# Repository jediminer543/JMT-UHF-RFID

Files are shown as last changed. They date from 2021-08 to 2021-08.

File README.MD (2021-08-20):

# The UHF-RFID project

This project aims to do build a working UHF RFID reader (ISO 18000-6C thing) using a pair of CC1101s.

But why the hell would you want to do this? Simple. The silicon to do UHF RFID tag reading goes for around $30 per chip in low volumes, dropping to $20 in high volumes. The entire main devboard, fully assembled, cost a grand total of $10 per board.

Given the anciliary components (MCU, Antennas, PowerRegs, PowerAmps, etc.) are likely to cost that again, BOM Cost for a reader built with this scheme is likely $20-30 total, which even at a 2.5x profit maring would still be competetive with the cheapest readers avalible on sites like Aliexpress.

## But why do you care?

UHF RFID allows for the reading of passive tags at up to 15m ranges for some tags. 15m would happen to helpfully cover most houses.

Further depending on which research you look at, these tags have localisability to below 10cm.

Combining these two features, if a many reader system were viable and cheap, it could make losing things a thing of the past. Or just make sure that places stay tidy

## Project state

I have the boards fabbed and assembled; I need to get some more RF stuff fabbed but it's just striplines so should be cheap to make.

Successful communication to the tags was achieved, but return linking failed due to the requirement for a circulator esque device, which has been designed acording to the specifications of [this paper](https://www.researchgate.net/publication/224684549_A_Passive_Circulator_for_RFID_Application_with_High_Isolation_using_a_Directional_Coupler) and simulated with QUCS. These still need to be fabricated.

The code for the project is very much unoptimised; spending far too long doing bitsetting, but this was done intentionally for ease of tweaking; future software improvements will occur if/when the project progresses.

## Why is this on github?

Two reasons. Firstly to share with the world so someone else can hopefully learn or develop something from it

Secondly, because I'm applying for some jobs and saying "here's a thing I made and the source for it" seems fun.

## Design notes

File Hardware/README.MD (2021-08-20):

## Hardware stuff

The devboard folder contains all the files used for the creation of the current devboard, including JLC assemblable gerbers.

The circulator folder contains the files for the circulator in theory, but the results have yet to be validated in the real world

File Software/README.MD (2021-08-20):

## Software

This is the currently built software; made to run on an ESP32 devkit and the dev boards used as part of the project

If you can find yourselves some SMA capible CC1101 boards then you can just use them instead. I couldn't which is why I built my own hardware.

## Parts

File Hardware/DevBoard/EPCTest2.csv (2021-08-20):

Comment | Designator | Footprint | LCSC | LCSC | Price | Field4 | Field5 | Field6 | Field7
100pF | C10,C26 | Capacitors_SMD:C_0603 |  | C14858 | 0.002882
27pF | C11,C12,C27,C28 | Capacitors_SMD:C_0603 |  | C1656 | 0.011736
100nF | C2,C18 | Capacitors_SMD:C_0603 |  | C14663
1pF | C3,C19 | Capacitors_SMD:C_0603 |  | C23969
12pF | C4,C20 | Capacitors_SMD:C_0603 |  | C38523
1.5pF | C5,C1,C21,C17 | Capacitors_SMD:C_0603 |  | C1639
3.3pF | C6,C22 | Capacitors_SMD:C_0603 |  | C85300
47pF | C7,C23 | Capacitors_SMD:C_0603 |  | C1671
DC | C8,C13,C14,C9,C15,C16,C24,C29,C30,C25,C31,C32 | Capacitors_SMD:C_0603 |  | C14663 | 0.007651
CommonSPI | J1 | Pin_Headers:Pin_Header_Straight_1x07_Pitch2.54mm |  | DNP | 0
GDO | J2 | Pin_Headers:Pin_Header_Straight_1x04_Pitch2.54mm |  | DNP | 0
CombOut | J3 | Connectors:SMA_THT_Jack_Straight |  | DNP | 1.12
Local RF Out | J4,J6 | Connectors:SMA_THT_Jack_Straight |  | DNP | 1.12
DigitalIO | J5,J7 | Pin_Headers:Pin_Header_Straight_1x08_Pitch2.54mm |  | DNP | 0
ISO_RX | JP1 | Resistors_SMD:R_0603 |  | DNP | 0.002705
ISO_TX | JP2 | Resistors_SMD:R_0603 |  | DNP | 0.002705
18nH | L2,L7,L9,L14 | Inductors_SMD:L_0603 |  | C86133 | 0.050628
12nH | L5,L1,L3,L4,L12,L8,L10,L11 | Inductors_SMD:L_0603 |  | C29258 | 0.034201
3.3nH | L6,L13 | Inductors_SMD:L_0603 |  | C1029 | 0.006151
PICross | R1 | Resistors_SMD:R_0603 |  | DNP | 0.005
PILeg | R3,R2 | Resistors_SMD:R_0603 |  | DNP | 0.005
TeeCross | R4,R5 | Resistors_SMD:R_0603 |  | DNP | 0.005
TeeLeg | R6 | Resistors_SMD:R_0603 |  | DNP | 0.005
56K | R7,R8 | Resistors_SMD:R_0603 |  | C23206 | 0.000769
CC1101 | U1,U2 | Housings_DFN_QFN:QFN-20-1EP_4x4mm_Pitch0.5mm |  | C29953 | 1.604545 | - | 55R2471 | QFN-20 | CC1101RGP
26Mhz | Y2,Y1 | Crystals:Crystal_SMD_3225-4pin_3.2x2.5mm |  | C70573 | 0.094375

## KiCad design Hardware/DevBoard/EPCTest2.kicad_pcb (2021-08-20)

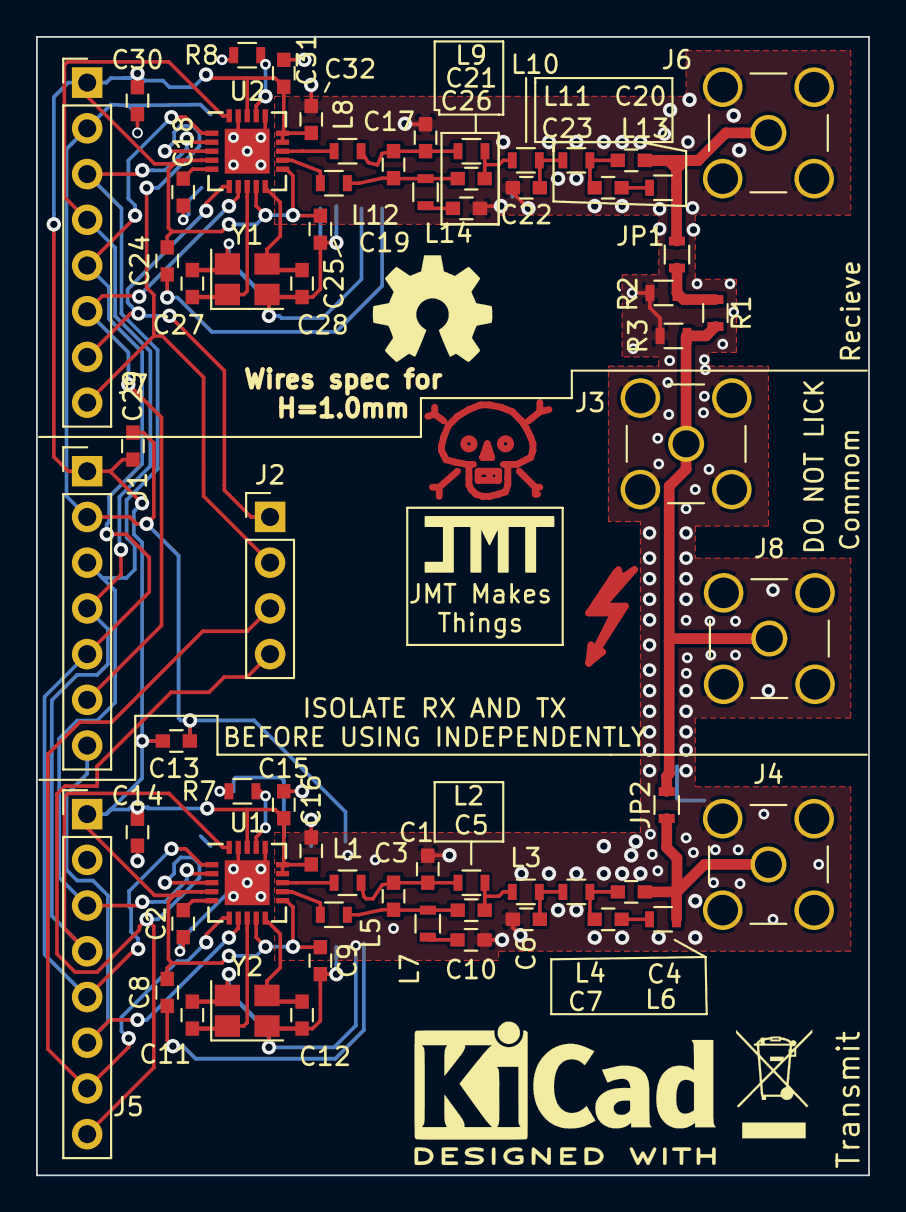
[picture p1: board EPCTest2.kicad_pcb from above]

Board: 2 copper layers, 46.2 x 63.2 mm, 70 parts (0 on the bottom side), 41 nets.

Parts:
 : WEEE; WEEE-Logo_4.2x6mm_SilkScreen
 #2: KiCad; KiCad-Logo2_8mm_SilkScreen
 #3: DANGER; Symbol_Danger_CopperTop_Small
 #4: OSHW; OSHW-Symbol_6.7x6mm_SilkScreen
C1, C5, C17, C21: 1.5pF; C_0603
C2, C18: 100nF; C_0603
C3, C19: 1pF; C_0603
C4, C20: 12pF; C_0603
C6, C22: 3.3pF; C_0603
C7, C23: 47pF; C_0603
C8, C9, C13, C14, C15, C16, C24, C25, C29, C30, C31, C32: DC; C_0603
C10, C26: 100pF; C_0603
C11, C12, C27, C28: 27pF; C_0603
DO NOT LICK: Zap; Symbol_Highvoltage_Type1_CopperTop_Small
J1: CommonSPI; Pin_Header_Straight_1x07_Pitch2.54mm
J2: GDO; Pin_Header_Straight_1x04_Pitch2.54mm
J3: CombOut; SMA_THT_Jack_Straight
J4, J6: Local RF Out; SMA_THT_Jack_Straight
J5, J7: DigitalIO; Pin_Header_Straight_1x08_Pitch2.54mm
J8: Amped In; SMA_THT_Jack_Straight
JP1: ISO_RX; R_0603
JP2: ISO_TX; R_0603
L1, L3, L4, L5, L8, L10, L11, L12: 12nH; L_0603
L2, L7, L9, L14: 18nH; L_0603
L6, L13: 3.3nH; L_0603
R1: PICross; R_0603
R2, R3: PILeg; R_0603
R7, R8: 56K; R_0603
U1, U2: CC1101; QFN-20-1EP_4x4mm_Pitch0.5mm
Y1, Y2: 26Mhz; Crystal_SMD_3225-4pin_3.2x2.5mm

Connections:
+3V3: C8.1, C9.1, C13.1, C14.1, C15.1, C16.1, C24.1, C25.1, C29.1, C30.1, C31.1, C32.1, J1.1, J5.1, J7.1, U1.4, U1.9, U1.11, U1.14, U1.15, U1.18, U2.4, U2.9, U2.11, U2.14, U2.15, U2.18
/CSnRX: J1.6, J7.6, U2.7
/CSnTX: J1.7, J5.6, U1.7
/GDO0_RX: J2.1, J7.7, U2.6
/GDO0_TX: J2.3, J5.7, U1.6
/GDO2_RX: J2.2, J7.8, U2.3
/GDO2_TX: J2.4, J5.8, U1.3
/MISO: J1.3, J5.3, J7.3, U1.2, U2.2
/MOSI: J1.4, J5.4, J7.4, U1.20, U2.20
/RFLeft/DCOUPL: C18.2, U2.5
/RFLeft/RBIAS: R8.2, U2.17
/RFLeft/RF1_N: C17.2, C19.1, L8.2, L9.1
/RFLeft/RF1_P: C19.2, C21.2, L12.1, L14.1
/RFLeft/RF_N: L8.1, U2.13
/RFLeft/RF_P: L12.2, U2.12
/RFLeft/RF_SE: C20.2, J6.1, JP1.1, L13.1
/RFLeft/XOSC1: C27.1, U2.8, Y1.1
/RFLeft/XOSC2: C28.1, U2.10, Y1.3
/RFRight/DCOUPL: C2.2, U1.5
/RFRight/RBIAS: R7.2, U1.17
/RFRight/RF1_N: C1.2, C3.1, L1.2, L2.1
/RFRight/RF1_P: C3.2, C5.2, L5.1, L7.1
/RFRight/RF_N: L1.1, U1.13
/RFRight/RF_P: L5.2, U1.12
/RFRight/RF_SE: C4.2, J4.1, JP2.1, L6.1
/RFRight/XOSC1: C11.1, U1.8, Y2.1
/RFRight/XOSC2: C12.1, U1.10, Y2.3
/RF_RX: JP1.2, R1.1, R2.2
/RF_RX_ATT: J3.1, J8.1, JP2.2, R1.2, R3.2
/SCLK: J1.5, J5.5, J7.5, U1.1, U2.1
GND: C1.1, C2.1, C6.2, C8.2, C9.2, C10.2, C11.2, C12.2, C13.2, C14.2, C15.2, C16.2, C17.1, C18.1, C22.2, C24.2, C25.2, C26.2, C27.2, C28.2, C29.2, C30.2, C31.2, C32.2, J1.2, J3.2, J4.2, J5.2, J6.2, J7.2, J8.2, R2.1, R3.1, R7.1, R8.1, U1.16, U1.19, U1.21, U2.16, U2.19, U2.21, Y1.2, Y1.4, Y2.2, Y2.4
unnamed: C4.1, C7.2, L4.2
unnamed: C5.1, L2.2, L3.1
unnamed: C6.1, L3.2, L4.1
unnamed: C7.1, L6.2
unnamed: C10.1, L7.2
unnamed: C20.1, C23.2, L11.2
unnamed: C21.1, L9.2, L10.1
unnamed: C22.1, L10.2, L11.1
unnamed: C23.1, L13.2
unnamed: C26.1, L14.2

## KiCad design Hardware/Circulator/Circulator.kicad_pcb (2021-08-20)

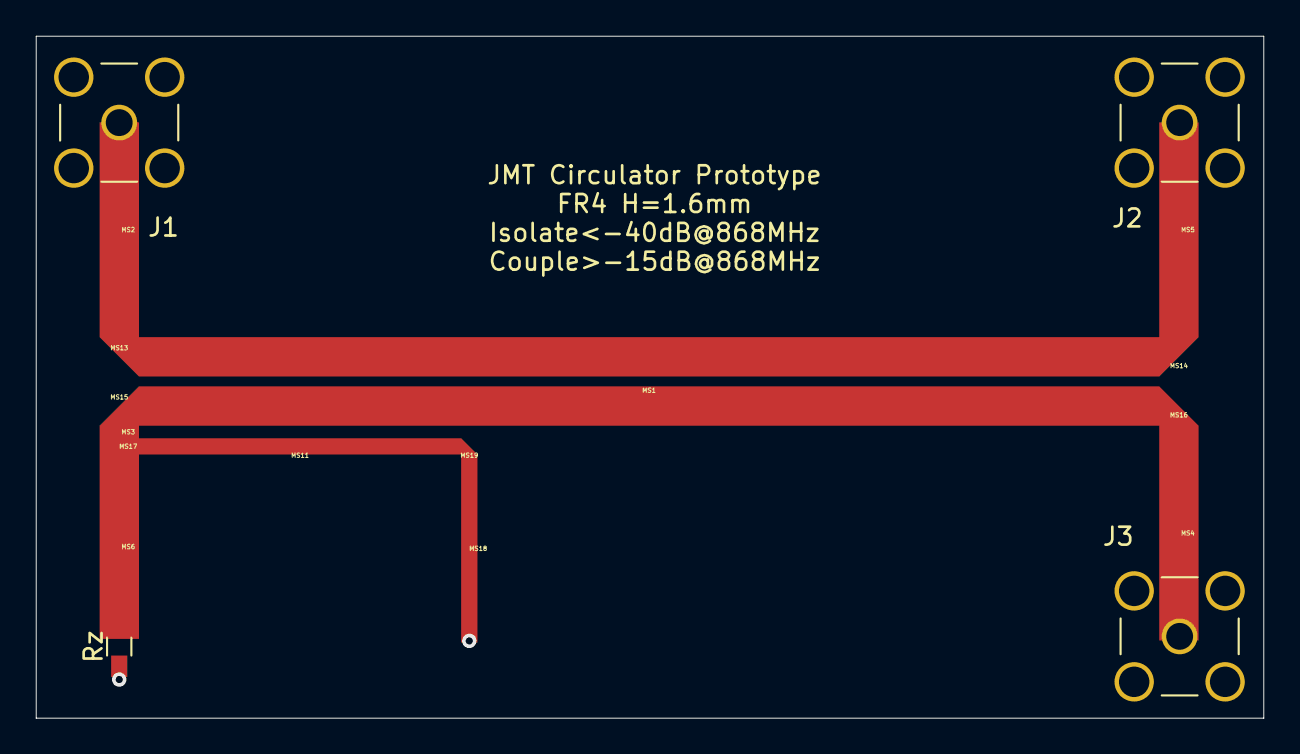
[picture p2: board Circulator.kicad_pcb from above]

Board: 2 copper layers, 68.6 x 38.1 mm, 18 parts (0 on the bottom side), 2 nets.

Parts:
J1, J2, J3: Conn_Coaxial; SMA_THT_Jack_Straight
MS1: microstrip_coupled_lines; MCOUPLED
MS2, MS3, MS4, MS5, MS6, MS11, MS18: microstrip_line; MLIN
MS13, MS14, MS15, MS16, MS19: microstrip_mittered_bend; MMBEND
MS17: microstrip_tee; MTEE
Rz: Rz; R_0603_HandSoldering

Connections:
GND: J1.2, J2.2, J3.1, J3.2, Rz.1
unnamed: J1.1, J2.1

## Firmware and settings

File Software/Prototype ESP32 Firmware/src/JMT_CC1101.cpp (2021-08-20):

#include "JMT_CC1101.h"
#include <Arduino.h>
#include <SPI.h>

uint8_t CC1101_COMMAND(SPIClass* spi, int CSn, uint8_t cmd) {
  spi->beginTransaction(SPISettings(CC1101_GETDR(cmd), MSBFIRST, SPI_MODE0));
  digitalWrite(CSn, LOW);
  uint8_t out = spi->transfer(cmd);
  digitalWrite(CSn, HIGH);
  spi->endTransaction();
  return out;
}

void CC1101_COMMAND(SPIClass* spi, int CSn, int len, uint8_t* dat) {
  spi->beginTransaction(SPISettings(CC1101_GETDR(*dat), MSBFIRST, SPI_MODE0));
  digitalWrite(CSn, LOW);
  for (int i = len-1; i >= 0; i--) {
    *(dat+i) = spi->transfer(*(dat+i));
  }
  digitalWrite(CSn, HIGH);
  spi->endTransaction();
}

void CC1101_COMMAND_REV(SPIClass* spi, int CSn, int len, uint8_t* dat) {
  spi->beginTransaction(SPISettings(CC1101_GETDR(*dat), MSBFIRST, SPI_MODE0));
  digitalWrite(CSn, LOW);
  for (int i = 0; i < len; i++) {
    *(dat+i) = spi->transfer(*(dat+i));
  }
  digitalWrite(CSn, HIGH);
  spi->endTransaction();
}

JCC1101::JCC1101(SPIClass* spi, uint8_t CSn) {
    this->spi = spi;
    this->CSn = CSn;
    pinMode(CSn, OUTPUT);
    digitalWrite(CSn, HIGH);
}

uint8_t JCC1101::command(uint8_t cmd) {
    spi->beginTransaction(SPISettings(CC1101_GETDR(cmd), MSBFIRST, SPI_MODE0));
    digitalWrite(CSn, LOW);
    uint8_t out = spi->transfer(cmd);
    digitalWrite(CSn, HIGH);
    spi->endTransaction();
    return out;
}

void JCC1101::command(int len, uint8_t* dat) {
    spi->beginTransaction(SPISettings(CC1101_GETDR(*dat), MSBFIRST, SPI_MODE0));
    digitalWrite(CSn, LOW);
    for (int i = len-1; i >= 0; i--) {
    *(dat+i) = spi->transfer(*(dat+i));
    }
    digitalWrite(CSn, HIGH);
    spi->endTransaction();
}

void JCC1101::commandRev(int len, uint8_t* dat) {
    spi->beginTransaction(SPISettings(CC1101_GETDR(*dat), MSBFIRST, SPI_MODE0));
    digitalWrite(CSn, LOW);
    for (int i = 0; i < len; i++) {
    *(dat+i) = spi->transfer(*(dat+i));
    }
    digitalWrite(CSn, HIGH);
    spi->endTransaction();
}

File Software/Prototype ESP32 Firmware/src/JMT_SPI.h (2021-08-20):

//SPI BIT ORDERING
#define JMT_SPI_LSBFIRST = 0;
#define JMT_SPI_MSBFIRST = 1;

//SPI MODE; NICKED FROM ARDUINO
#define JMT_SPI_MODE0 = 0;
#define JMT_SPI_MODE1 = 1;
#define JMT_SPI_MODE2 = 2;
#define JMT_SPI_MODE3 = 3;

/**
 * Standard SPI class
 * 
 * Cross platform
 */
class JMTSPI {
  public:
    virtual void beginTransaction() = 0;
    virtual void endTransaction() = 1;
    virtual uint8_t transfer(uint8_t data) = 2;
} JSPI;

/**
 * Arduino version
 */
class JMTASPI : public JMTSPI {
    SPIClass* spi;
    uint8_t pin;
  public:
    JMTASPI(SPIClass* spi, uint8_t pin) {
      this.spi = spi;
      this.pin = pin;
    }
    virtual void beginTransaction() {
      
    }
    virtual void endTransaction();
    virtual uint8_t transfer(uint8_t data)
} JASPI;
